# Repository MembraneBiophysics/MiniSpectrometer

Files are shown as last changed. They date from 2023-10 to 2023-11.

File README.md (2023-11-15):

# Mini Spectrometer

A low cost, low power, portable spectrometer for education and research.

For more information please see www.minispectrometer.co.uk

All the CAD files and code needed to make a range of different mini-spectrometers are included in the folders here. We'll be developing project instructions and information packs over the next little while but if you have any questions or would like any more information, please feel free to get in touch (contact details on the website link above).

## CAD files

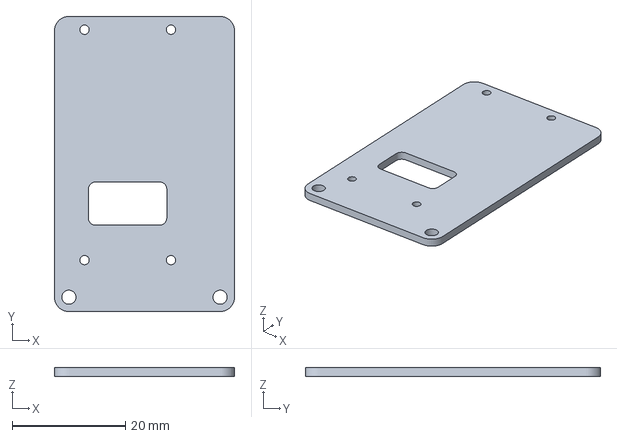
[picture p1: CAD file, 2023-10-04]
CAD files/3mf files - for 3D printing/Arduino Nano spacer - 3D.3mf
31.8 x 52.1 x 1.50 mm

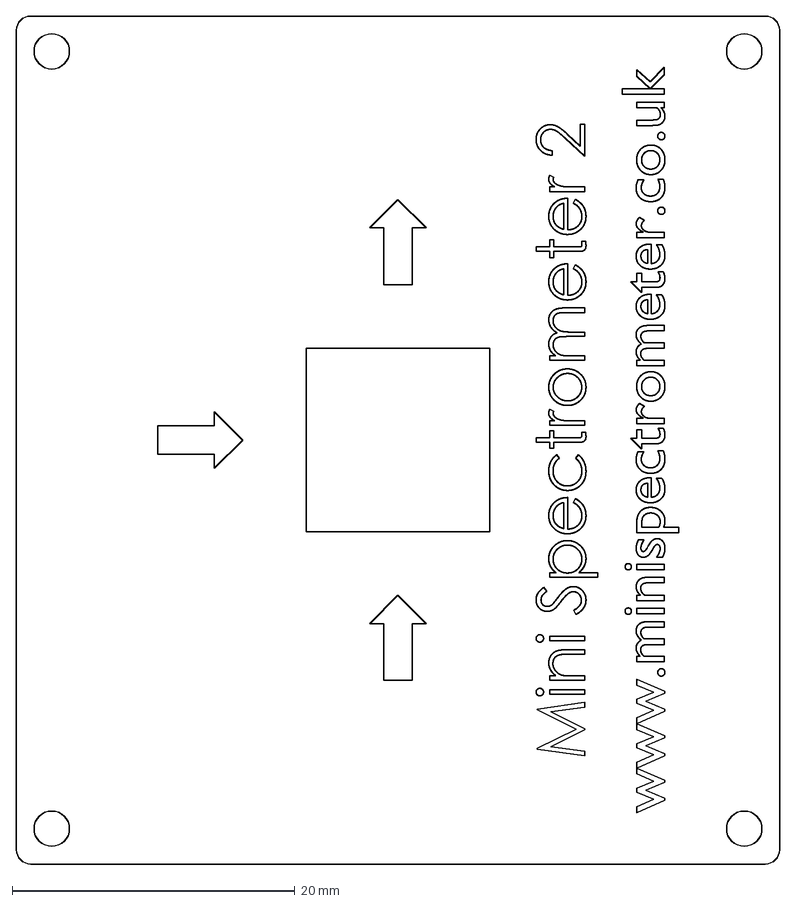
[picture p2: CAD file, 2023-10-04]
CAD files/DXF and EPS files - for laser cutting/Mini Spectrometer Lid - mm units.dxf
54.0 x 60.0 mm

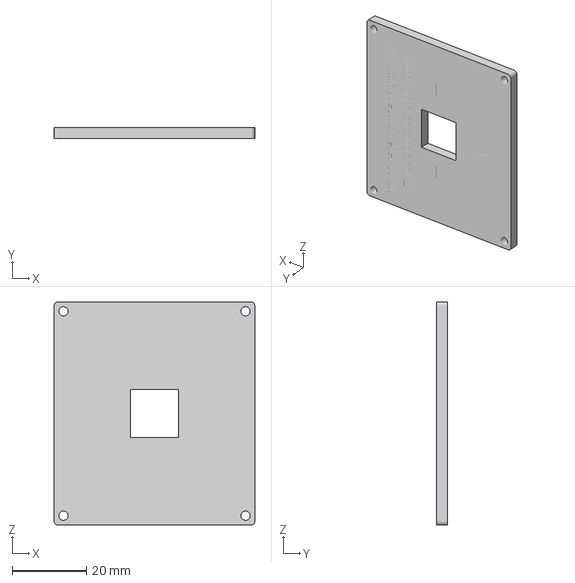
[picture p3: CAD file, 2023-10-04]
CAD files/3mf files - for 3D printing/Mini Spectrometer Lid - 3D.3mf
54.0 x 3.00 x 60.0 mm

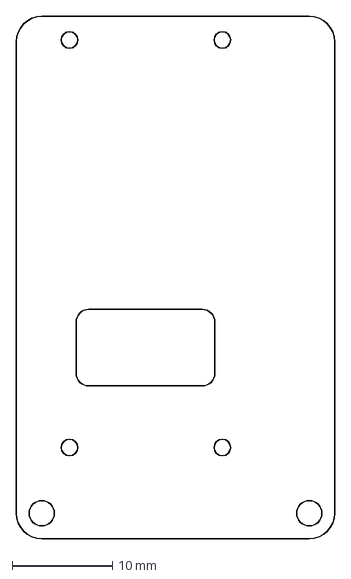
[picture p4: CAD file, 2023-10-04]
CAD files/DXF and EPS files - for laser cutting/Arduino Nano Spacer - mm units.dxf
31.8 x 52.1 mm

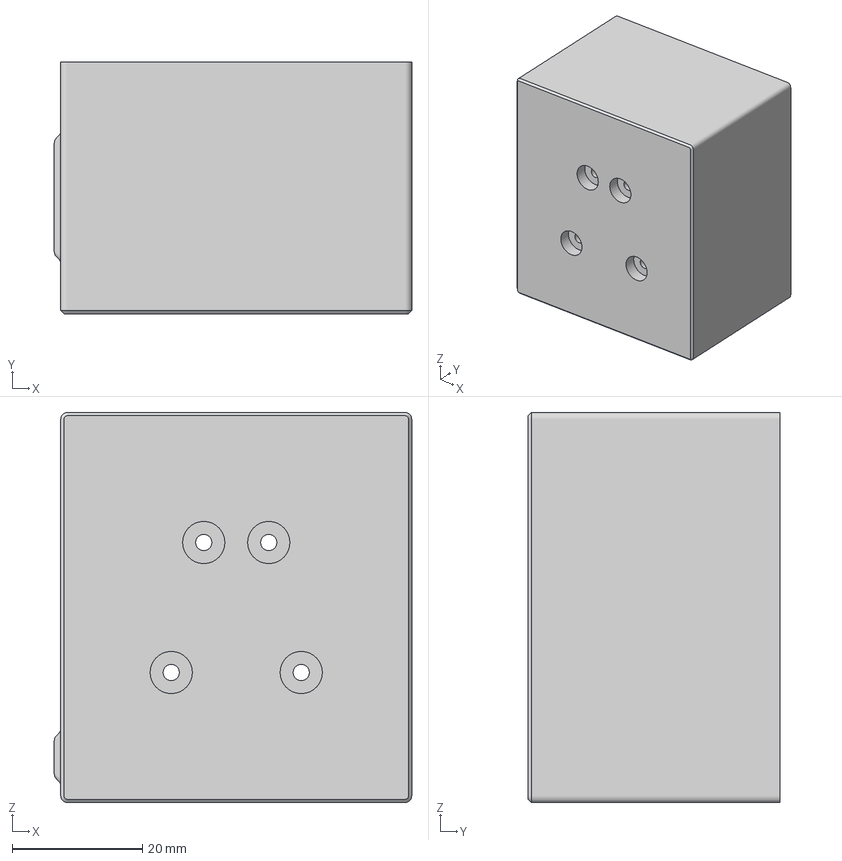
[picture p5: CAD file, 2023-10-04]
CAD files/3mf files - for 3D printing/Mini Spectrometer Box.3mf
55.0 x 38.8 x 60.0 mm

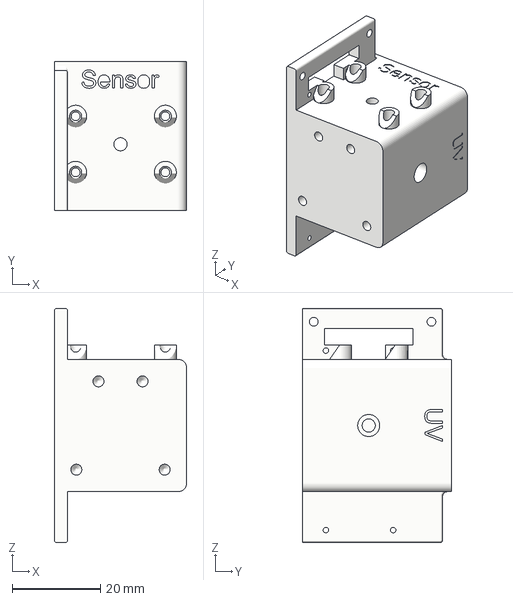
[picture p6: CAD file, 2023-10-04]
CAD files/3mf files - for 3D printing/Mini Spectrometer Core.3mf
30.0 x 33.8 x 53.0 mm

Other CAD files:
CAD files/STL files - for 3D printing/Arduino Nano spacer.stl
CAD files/Autodesk Fusion 360 files/Arduino Nano Spacer - No circuit board.f3d
CAD files/Autodesk Fusion 360 files/Mini Spectrometer Box.f3d
CAD files/Autodesk Fusion 360 files/Mini Spectrometer Core.f3d
CAD files/Autodesk Fusion 360 files/Mini Spectrometer Lid.f3d
CAD files/STL files - for 3D printing/Mini Spectrometer Box.stl
CAD files/STL files - for 3D printing/Mini Spectrometer Core.stl
CAD files/STL files - for 3D printing/Mini Spectrometer Lid - 3D.stl
Electronics/Autodesk Fusion 360 PCB files/Mini Spectrometer LED Circuit Board.f3z
Electronics/Autodesk Fusion 360 PCB files/Mini Spectrometer Main Circuit Board.f3z

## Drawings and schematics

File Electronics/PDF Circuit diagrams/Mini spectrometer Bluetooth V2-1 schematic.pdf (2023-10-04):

# Nick Brooks 4 Oct 2023 Use STEMMA QT socket to connect to sensor board

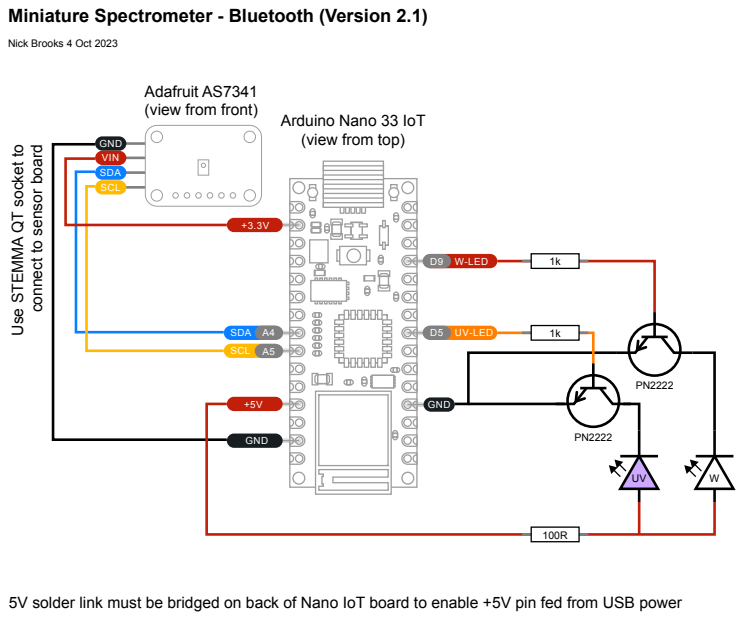
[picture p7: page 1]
GND; SDA SCL; W-LED; UV-LED; GND VIN SDA SCL

Miniature Spectrometer - Bluetooth (Version 2.1)

Adafruit AS7341
(view from front)

Arduino Nano 33 IoT
(view from top)

5V solder link must be bridged on back of Nano IoT board to enable +5V pin fed from USB power

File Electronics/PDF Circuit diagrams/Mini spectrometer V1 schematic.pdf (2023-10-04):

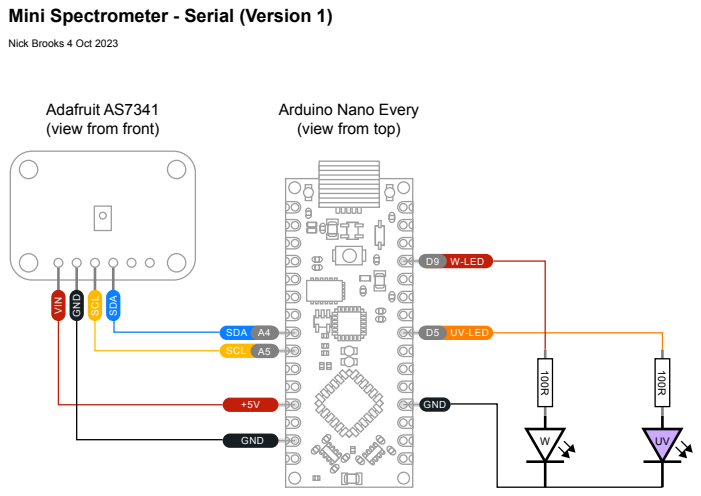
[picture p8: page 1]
GND; SDA SCL; W-LED; UV-LED; VIN; SCL; SDA

Mini Spectrometer - Serial (Version 1)

Nick Brooks 4 Oct 2023

Adafruit AS7341
(view from front)

Arduino Nano Every
(view from top)

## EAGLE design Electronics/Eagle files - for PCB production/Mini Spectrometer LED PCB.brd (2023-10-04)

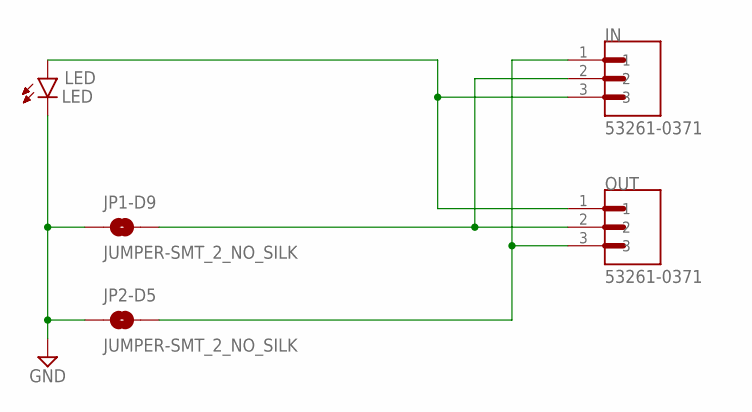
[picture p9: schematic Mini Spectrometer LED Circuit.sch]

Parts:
IN: 53261-0371; MOLEX_53261-0371
JP1-D9, JP2-D5: JUMPER-SMT_2_NO_SILK; SMT-JUMPER_2_NO_SILK
LED: LED; LEDRD254W60D565H860B_W
OUT: 53261-0371; MOLEX_53261-0371

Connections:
GND: JP1-D9.1, JP2-D5.1, LED.2 (C)
unnamed: IN.3, LED.1 (A), OUT.1
unnamed: IN.2, JP1-D9.2, OUT.2
unnamed: IN.1, JP2-D5.2, OUT.3

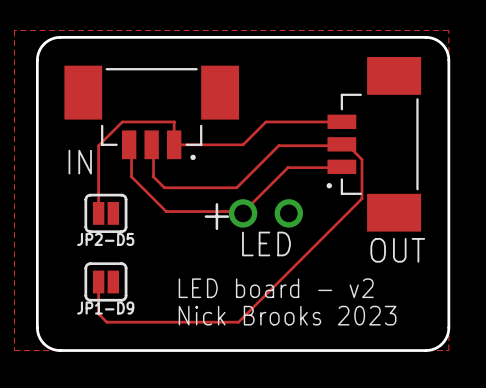
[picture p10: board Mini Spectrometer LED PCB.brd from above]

Board: 2 copper layers, 22.9 x 17.4 mm, 5 parts (1 on the bottom side), 4 nets.

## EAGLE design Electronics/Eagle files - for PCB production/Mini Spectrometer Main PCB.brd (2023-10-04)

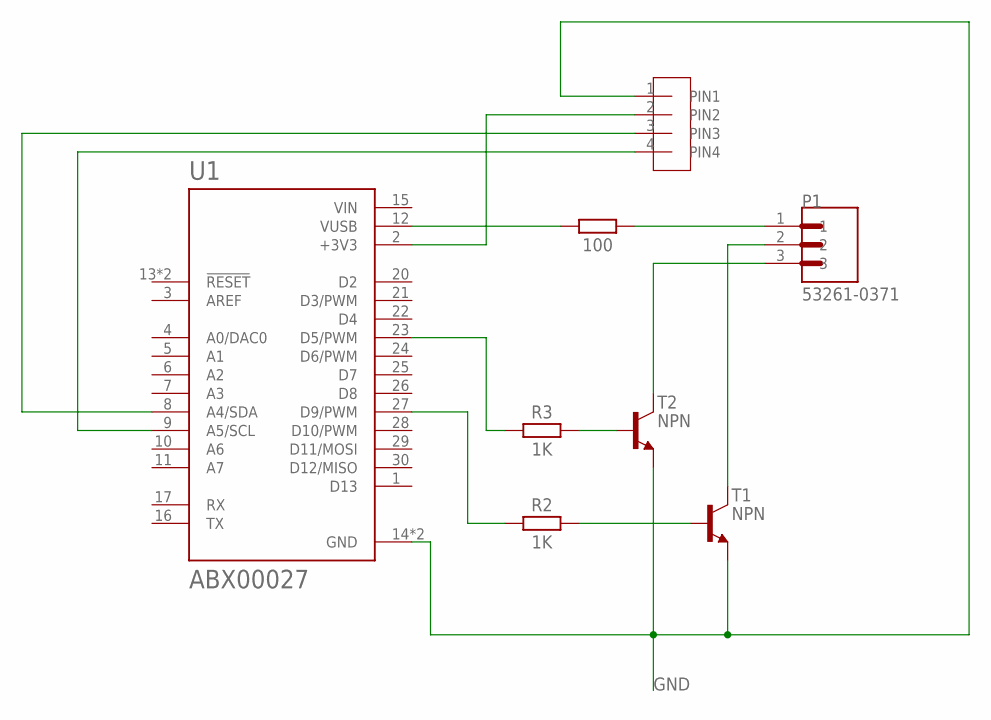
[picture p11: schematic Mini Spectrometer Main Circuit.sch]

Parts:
J1: JST-SH-4WAY-2; JST_SM04B-SRSS-TB_LF__SN_
P1: 53261-0371; MOLEX_53261-0371
R1: 100; RESC3216X70
R2, R3: 1K; RESC1005X40
T1, T2: NPN; SOT95P237X112-3N
U1: ABX00027; MODULE_ABX00027

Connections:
GND: J1.1 (PIN1), T1.2 (E), T2.2 (E), U1.14 (GND), U1.19 (GND)
unnamed: R1.1, U1.12 (VUSB)
unnamed: R2.1, U1.27 (D9/PWM)
unnamed: R3.1, U1.23 (D5/PWM)
unnamed: R2.2, T1.1 (B)
unnamed: R3.2, T2.1 (B)
unnamed: J1.2 (PIN2), U1.2 (+3V3)
unnamed: J1.3 (PIN3), U1.8 (A4/SDA)
unnamed: J1.4 (PIN4), U1.9 (A5/SCL)
unnamed: P1.1, R1.2
unnamed: P1.2, T1.3 (C)
unnamed: P1.3, T2.3 (C)
VIN: U1.15 (VIN)

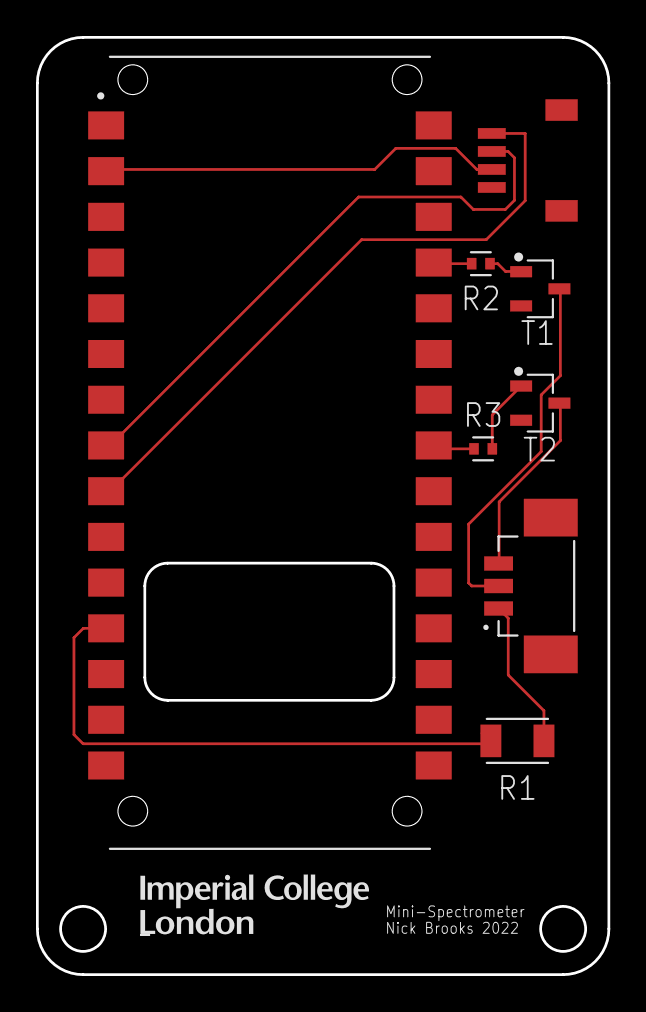
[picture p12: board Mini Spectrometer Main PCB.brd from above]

Board: 2 copper layers, 31.8 x 52.1 mm, 8 parts (0 on the bottom side), 12 nets.

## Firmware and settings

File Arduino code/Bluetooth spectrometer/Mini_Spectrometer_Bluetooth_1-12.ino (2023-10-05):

// Imperial College London - Department of Chemistry
// Mini Spectrometer - Bluetooth
// Nick Brooks 2023
// Version NB1.12 5-10-23

#include <Adafruit_AS7341.h>
#include <ArduinoBLE.h>

/************* BLE UUIDs ******************/

BLEService spectrometerService("9ce6c285-27c0-4225-a406-39a1f545b62d"); // BLE Spectrometer Service

BLEUnsignedIntCharacteristic spectrometerLED1("a1fefc52-bed5-4e1e-8b51-69f71e1b79f5", BLERead | BLEWrite);
BLEUnsignedIntCharacteristic spectrometerLED2("2d69768c-3668-4dfd-82b5-01d1f75b917f", BLERead | BLEWrite);
BLEUnsignedIntCharacteristic spectrometerGain("9ec03f4a-5013-48af-99f6-581b976540d1", BLERead | BLEWrite);
BLEUnsignedIntCharacteristic spectrometerExposure("62b16ea6-4210-44bd-b0e0-adac3abc6744", BLERead | BLEWrite);
BLECharacteristic spectrometerDetector("63b118cc-7df1-498c-be35-dfb15534f55c", BLERead | BLENotify, 16);


/************* AS7341 variables ******************/

Adafruit_AS7341 as7341;

const long interval = 20;           // minimum time between updates (milliseconds)
unsigned long previousMillis = 0;     // previous loop time

int val;

byte sensorData[16];

const int transmissionLedPin = 9; // pin to use for the transmission LED
const int fluorescenceLedPin = 5; // pin to use for the UV LED

// variables to hold sensor values.
uint16_t readings[12];
uint16_t stepSize = 3596; //This sets the resolution of the exposure time (see AS7341 documentation for more info)
/*
 10ms - 3596
 15ms -  5395
 20ms -  7193
 25ms -  8992
 30ms -  10790
 35ms -  12589
 40ms -  14387
 45ms -  16186
 50ms -  17985
 */


/********* Functions to run the spectrometer and LEDs *********/

void spectrometerInfo (void)
{
  Serial.println("Imperial College London - Department of Chemistry");
  Serial.println("Mini Spectrometer Bluetooth - Nick Brooks");
  Serial.println("Version NB1.12 - 05-10-23");
}

void setFluorescenceBrightness (int brightness) {
  analogWrite(fluorescenceLedPin, brightness);
  Serial.print("Fluorescence LED brightness: "); Serial.println(constrain(int(brightness),0,255));
  spectrometerLED2.writeValue(constrain(int(brightness),0,255));
}

void setTransmissionBrightness (int brightness) {
  analogWrite(transmissionLedPin, brightness);
  Serial.print("Transmission LED brightness: "); Serial.println(constrain(int(brightness),0,255));
  spectrometerLED1.writeValue(constrain(int(brightness),0,255));
}

void sensorRead(void) {
  bool timeOutFlag = timeOutCheck();
  if(as7341.checkReadingProgress() || timeOutFlag )
  { 
    digitalWrite(LED_BUILTIN, HIGH);
    if(timeOutFlag)
    {} //Recover/restart
    
    as7341.getAllChannels(readings);

    sensorData[0] = lowByte(readings[0]);
    sensorData[1] = highByte(readings[0]);
    sensorData[2] = lowByte(readings[1]);
    sensorData[3] = highByte(readings[1]);
    sensorData[4] = lowByte(readings[2]);
    sensorData[5] = highByte(readings[2]);
    sensorData[6] = lowByte(readings[3]);
    sensorData[7] = highByte(readings[3]);
    sensorData[8] = lowByte(readings[6]);
    sensorData[9] = highByte(readings[6]);
    sensorData[10] = lowByte(readings[7]);
    sensorData[11] = highByte(readings[7]);
    sensorData[12] = lowByte(readings[8]);
    sensorData[13] = highByte(readings[8]);
    sensorData[14] = lowByte(readings[9]);
    sensorData[15] = highByte(readings[9]);
    
    spectrometerDetector.writeValue(sensorData,16);
    as7341.startReading();
  }
  else {
        digitalWrite(LED_BUILTIN, LOW);
  }
}

bool timeOutCheck()
{
  return false;
}

void setExposure (int exposure) {
  as7341.setATIME(int((exposure/(0.00278*(stepSize+1))-1)));
  Serial.print (("Integration time: "));
  Serial.print ((1+long(as7341.getATIME()))*(1+long(as7341.getASTEP()))*0.00278);
  Serial.println ((" ms"));
  exposure = int((1+long(as7341.getATIME()))*(1+long(as7341.getASTEP()))*0.00278);
  spectrometerExposure.writeValue(round(((1+long(as7341.getATIME()))*(1+long(as7341.getASTEP()))*0.00278)));
}

void setGain (int gainIn) {
  switch (int(gainIn)) {
    case 0:
      as7341.setGain(AS7341_GAIN_0_5X);    // 0.5x gain
      break;
    case 1:
      as7341.setGain(AS7341_GAIN_1X);      // 1x gain
      break;
    case 2:
      as7341.setGain(AS7341_GAIN_2X);   // 2x gain
      break;
    case 3:
      as7341.setGain(AS7341_GAIN_4X);   // 4x gain
      break;
    case 4:
      as7341.setGain(AS7341_GAIN_8X);    // 8x gain
      break;
    case 5:
      as7341.setGain(AS7341_GAIN_16X);      // 16x gain
      break;
    case 6:
      as7341.setGain(AS7341_GAIN_32X);   // 32x gain
      break;
    case 7:
      as7341.setGain(AS7341_GAIN_64X);   // 64x gain
      break;
    case 8:
      as7341.setGain(AS7341_GAIN_128X);      // 128x gain
      break;
    case 9:
      as7341.setGain(AS7341_GAIN_256X);   // 256x gain
      break;
    case 10:
      as7341.setGain(AS7341_GAIN_512X);   // 512x gain
      break;
    }

    Serial.print  (F("Gain: "));
    as7341_gain_t gainOut = as7341.getGain();
    switch(gainOut)
    {
      case AS7341_GAIN_0_5X:
        Serial.println(F("0.5x"));
        spectrometerGain.writeValue(0);
        break;
      case AS7341_GAIN_1X:
        Serial.println(F("1x"));
        spectrometerGain.writeValue(1);
        break;
      case AS7341_GAIN_2X:
        Serial.println(F("2x"));
        spectrometerGain.writeValue(2);
        break;
      case AS7341_GAIN_4X:
        Serial.println(F("4x"));
        spectrometerGain.writeValue(3);
        break;
      case AS7341_GAIN_8X:
        Serial.println(F("8x"));
        spectrometerGain.writeValue(4);
        break;
      case AS7341_GAIN_16X:
        Serial.println(F("16x"));
        spectrometerGain.writeValue(5);
        break;
      case AS7341_GAIN_32X:
        Serial.println(F("32x"));
        spectrometerGain.writeValue(6);
        break;
      case AS7341_GAIN_64X:
        Serial.println(F("64x"));
        spectrometerGain.writeValue(7);
        break;
      case AS7341_GAIN_128X:
        Serial.println(F("128x"));
        spectrometerGain.writeValue(8);
        break;
      case AS7341_GAIN_256X:
        Serial.println(F("256x"));
        spectrometerGain.writeValue(9);
        break;
      case AS7341_GAIN_512X:
        Serial.println(F("512x"));
        spectrometerGain.writeValue(10);
        break;
    }
}

void displaySensorDetails(void) {
    Serial.println  (F("Sensor: AS7341"));
    Serial.println  (F("Driver Ver: 1"));
    Serial.println  (F("Unique ID: 7341"));
    Serial.println  (F("Max Value: 65535"));
    Serial.println  (F("Min Value: 0"));
    Serial.println  (F("Resolution: 1"));
}

void setup() {
  pinMode(9, OUTPUT);
  pinMode(5, OUTPUT);
  pinMode(2, INPUT);
  pinMode(LED_BUILTIN, OUTPUT);
  Serial.begin(115200);

  delay(2000);
  
  Serial.println("Mini Spectrometer Serial Started");
  spectrometerInfo();
    if (!as7341.begin()){
    Serial.println("Could not find AS7341");
    while (1) { delay(10); }
  }


   // begin BLE initialization
   
  if (!BLE.begin()) {
    Serial.println("starting BLE failed!");
    while (1);
  }

  Serial.println("Bluetooth Started");

  // set advertised local name and service UUID for spectrometer functions:
  BLE.setLocalName("Mini Spectrometer");
  BLE.setDeviceName("Mini Spectrometer");
  BLE.setAdvertisedService(spectrometerService);

  // add the characteristic to the service
  spectrometerService.addCharacteristic(spectrometerLED1);
  spectrometerService.addCharacteristic(spectrometerLED2);
  spectrometerService.addCharacteristic(spectrometerGain);
  spectrometerService.addCharacteristic(spectrometerExposure);
  spectrometerService.addCharacteristic(spectrometerDetector);

  // add service
  BLE.addService(spectrometerService);


  // set the initial value for the characeristic:

  as7341.setASTEP(stepSize);
  setGain(7);
  setExposure(100);
  
  setFluorescenceBrightness(0);
  setTransmissionBrightness(0);

  // start advertising
  BLE.advertise();

  Serial.println("BLE Spectrometer Peripheral Started");
}


void loop() {
  // listen for BLE peripherals to connect:
  BLEDevice central = BLE.central();

  // if a central is connected to peripheral:
  if (central) {
    Serial.print("Connected to central: ");
    // print the central's MAC address:
    Serial.println(central.address());

    // while the central is still connected to peripheral:
    while (central.connected()) {

      sensorRead();
      
      // if the remote device wrote to the characteristic,
      // use the value to control the LED:
      if (spectrometerLED1.written()) {
        val = spectrometerLED1.value();
        setTransmissionBrightness (val);
      }

      if (spectrometerLED2.written()) {
        val = spectrometerLED2.value();
        setFluorescenceBrightness (val);
      }

      if (spectrometerGain.written()) {
        val = spectrometerGain.value();
          setGain (val);
      }

      if (spectrometerExposure.written()) {
        val = spectrometerExposure.value();
        setExposure(val);
      }

      unsigned long currentMillis = millis();

      while (currentMillis - previousMillis < interval) {
        currentMillis = millis();
        delay(10);
      }

      previousMillis = currentMillis;          
    }

    // when the central disconnects, print it out:
    Serial.print(F("Disconnected from central: "));
    Serial.println(central.address());
  }
}

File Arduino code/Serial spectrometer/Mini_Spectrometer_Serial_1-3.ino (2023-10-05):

// Mini-Spectrometer Version 1 Arduino Firmware
// Imperial College London - Department of Chemistry
// Mini Spectrometer
// Nick Brooks 2021
// Version NB1.3 30-1-21

#include <Adafruit_AS7341.h>

Adafruit_AS7341 as7341;

const byte numChars = 32;
char receivedChars[numChars];

// variables to hold the parsed data
char messageFromPC = 0;
int integerFromPC = 0;
float floatFromPC = 0.0;

// variables to hold values.
uint16_t readings[12];
uint16_t stepSize = 9999; //This sets the resolution of the exposure time (see AS7341 documentation for more info)

boolean newData = false;

/********* Functions to run the spectrometer and LEDs *********/

void spectrometerInfo (void)
{
  Serial.println("Imperial College London - Department of Chemistry");
  Serial.println("Mini Spectrometer - Nick Brooks");
  Serial.println("Version NB1.3 - 30-1-21");
}

void setFluorescenceBrightness (float brightness) {
  analogWrite(5, brightness);
  Serial.print("Fluorescence LED brightness: "); Serial.println(constrain(int(brightness),0,255));
}

void setTransmissionBrightness (float brightness) {
  analogWrite(9, brightness);
  Serial.print("Transmission LED brightness: "); Serial.println(constrain(int(brightness),0,255));
}


/********* Functions to run the AS7341 sensor *********/

void sensorRead(void) {
  digitalWrite(LED_BUILTIN, HIGH);
    if (!as7341.readAllChannels(readings)){
    Serial.println("Error reading all channels!");
    digitalWrite(LED_BUILTIN, LOW);
    return;
  }
    digitalWrite(LED_BUILTIN, LOW);

    Serial.print("ADC0/F1 415nm : ");
    Serial.println(readings[0]);
    Serial.print("ADC1/F2 445nm : ");
    Serial.println(readings[1]);
    Serial.print("ADC2/F3 480nm : ");
    Serial.println(readings[2]);
    Serial.print("ADC3/F4 515nm : ");
    Serial.println(readings[3]);
    Serial.print("ADC0/F5 555nm : ");

  /*
  // we skip the first set of duplicate clear/NIR readings
  Serial.print("ADC4/Clear-");
  Serial.println(readings[4]);
  Serial.print("ADC5/NIR-");
  Serial.println(readings[5]);
  */

    Serial.println(readings[6]);
    Serial.print("ADC1/F6 590nm : ");
    Serial.println(readings[7]);
    Serial.print("ADC2/F7 630nm : ");
    Serial.println(readings[8]);
    Serial.print("ADC3/F8 680nm : ");
    Serial.println(readings[9]);
    Serial.print("ADC4/Clear    : ");
    Serial.println(readings[10]);
    Serial.print("ADC5/NIR      : ");
    Serial.println(readings[11]);
}

void setExposure (float exposure) {
  as7341.setATIME(int((exposure*1000)/(2.78*10000)));
  Serial.print (("Integration time: "));
  Serial.print ((1+long(as7341.getATIME()))*(1+long(as7341.getASTEP()))*0.00278);
  Serial.println ((" ms"));
}

void setGain (float gainIn) {
  switch (int(gainIn)) {
    case 0:
      as7341.setGain(AS7341_GAIN_0_5X);    // 0.5x gain
      break;
    case 1:
      as7341.setGain(AS7341_GAIN_1X);      // 1x gain
      break;
    case 2:
      as7341.setGain(AS7341_GAIN_2X);   // 2x gain
      break;
    case 3:
      as7341.setGain(AS7341_GAIN_4X);   // 4x gain
      break;
    case 4:
      as7341.setGain(AS7341_GAIN_8X);    // 8x gain
      break;
    case 5:
      as7341.setGain(AS7341_GAIN_16X);      // 16x gain
      break;
    case 6:
      as7341.setGain(AS7341_GAIN_32X);   // 32x gain
      break;
    case 7:
      as7341.setGain(AS7341_GAIN_64X);   // 64x gain
      break;
    case 8:
      as7341.setGain(AS7341_GAIN_128X);      // 128x gain
      break;
    case 9:
      as7341.setGain(AS7341_GAIN_256X);   // 256x gain
      break;
    case 10:
      as7341.setGain(AS7341_GAIN_512X);   // 512x gain
      break;
    }
    Serial.print  (F("Gain: "));
    as7341_gain_t gainOut = as7341.getGain();
    switch(gainOut)
    {
      case AS7341_GAIN_0_5X:
        Serial.println(F("0.5x"));
        break;
      case AS7341_GAIN_1X:
        Serial.println(F("1x"));
        break;
      case AS7341_GAIN_2X:
        Serial.println(F("2x"));
        break;
      case AS7341_GAIN_4X:
        Serial.println(F("4x"));
        break;
      case AS7341_GAIN_8X:
        Serial.println(F("8x"));
        break;
      case AS7341_GAIN_16X:
        Serial.println(F("16x"));
        break;
      case AS7341_GAIN_32X:
        Serial.println(F("32x"));
        break;
      case AS7341_GAIN_64X:
        Serial.println(F("64x"));
        break;
      case AS7341_GAIN_128X:
        Serial.println(F("128x"));
        break;
      case AS7341_GAIN_256X:
        Serial.println(F("256x"));
        break;
      case AS7341_GAIN_512X:
        Serial.println(F("512x"));
        break;
    }
}

void displaySensorDetails(void) {
  Serial.println  (F("Sensor: AS7341"));
    Serial.println  (F("Driver Ver: 1"));
    Serial.println  (F("Unique ID: 7341"));
    Serial.println  (F("Max Value: 65535"));
    Serial.println  (F("Min Value: 0"));
    Serial.println  (F("Resolution: 1"));
}


/********* Functions to handle serial communication with the computer *********/

// Receive data and extract the section delimited by <> marks

void recvWithStartEndMarkers() {
  static boolean recvInProgress = false;
  static byte ndx = 0;
  char startMarker = '<';
  char endMarker = '>';
  char rc;

  while (Serial.available() > 0 && newData == false) {
    rc = Serial.read();

    if (recvInProgress == true) {
      if (rc != endMarker) {
        receivedChars[ndx] = rc;
        ndx++;
        if (ndx >= numChars) {
          ndx = numChars - 1;
        }
      }
      else {
        receivedChars[ndx] = '\0'; // terminate the string
        recvInProgress = false;
        ndx = 0;
        newData = true;
      }
    }

    else if (rc == startMarker) {
      recvInProgress = true;
    }
  }
}

// Split received line from computer into command and data

void parseData() {      // split the data into its parts

  char* atofIndx;

  //First character represents command
  messageFromPC = receivedChars[0];

  //Remainder of received data converted to number
  atofIndx = receivedChars + 1;
  floatFromPC = atof(atofIndx);

}

// Process commands received from the computer

void showParsedData() {
  /*
    Serial.print("Message ");
    Serial.println(messageFromPC);
    Serial.print("Float ");
    Serial.println(floatFromPC);
  */

  if (messageFromPC == 'R') {
    sensorRead();
  }

  else if (messageFromPC == 'D'){
    displaySensorDetails();
  }

  else if (messageFromPC == 'F'){
    setFluorescenceBrightness (floatFromPC);
  }

  else if (messageFromPC == 'T'){
    setTransmissionBrightness (floatFromPC);
  }

  else if (messageFromPC == 'E'){
    setExposure (floatFromPC);
  }

  else if (messageFromPC == 'G'){
    setGain (floatFromPC);
  }

  else if (messageFromPC == 'I'){
      spectrometerInfo();
  }

  else {
    Serial.println("?");
  }

}


/********* Setup and loop functions run directly by the Arduino *********/
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

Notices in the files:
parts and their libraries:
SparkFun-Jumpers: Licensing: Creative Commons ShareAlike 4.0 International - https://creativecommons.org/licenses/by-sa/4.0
